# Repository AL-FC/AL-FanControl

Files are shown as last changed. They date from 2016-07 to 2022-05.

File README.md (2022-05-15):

# AL-FanControl

An application-level fan control for desktop PCs
    using Linux, Python, Arduino and PWM fans.

## Architecture

AL-FanControl controls fans according to the system temperature.
The image below shows an exemplary setup of AL-FanControl
    with three processors and two fans.

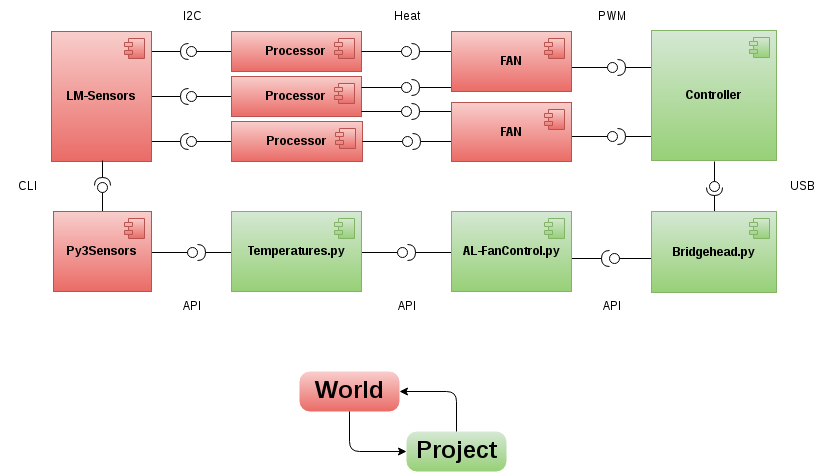
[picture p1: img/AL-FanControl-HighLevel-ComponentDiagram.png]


The main heat sources in modern computers usually expose some sensors via I2C.
These sensors can be read using LM-Sensors via an command line interface.
Py3Sensors provides an API to Python2 and Python3 appications.
This project's `Temperatures.py` reduces Py3Sensors API to temperature sensors.
This project's main application is `AL-FanControl.py`,
    which reacts to changed temperatures with changing the fan setpoints.
To send the setpoints to the controller,
    it uses the API of the `Bridgehead.py`.
The `Bridgehead.py` uses a serial interface (USB)
    to transfer the setpoints to the controller.
The controller controls the fans
    by setting its PWM outputs according to the setpoints.
All fans dissipate heat from surrounding processors.

## Rationale

PC cooling has always been an area of constant change.
In the past,
    ever more power hungry CPUs have lead to
    sophisticated cooling techology.
In combination with more efficient CPUs
    this has enabled smaller and quieter cooling,
    in recent years.
Yet,
    desktop PCs continue to be
    loud at idle and hot under load.
This is an attempt
    at reinventing fan control.
I hope to provoke
    a change in the way we control our fans
    that I feel is long overdue.

Plugging PWM fans into mainboards is a gamble,
    because many built-in fan control do not work properly.
Often PC users are are plagued by
    unnecessary fan noise at idle,
    nervously accelerating fans under short-time load and
    high temperatures at precious hardware.
When swapping
    mainboards, fans or operating systems,
    a previously well-working setup cam misbehave.
Fan controls can be much better and reliable.

Mainboards often only provide a few fan connectors,
    usually three or four.
PC cases come in a plethora of designs
    that feature anywhere from 0 to arbitrarily many fans.
So mainboards
    are notoriously underspecified
    for complex PC builds.
Dedicated hardware
    can control
    the fans
        of a PC
    more scalable
    than mainboards.

The electric motors
    of modern PC fans
    can be regulated via the voltage applied to them.
However,
    many fans
    are not able to
    spin up
    at low voltages.
Assuming fans to be running when they actually fail to spin up
    may lead to unintended actions.
For example,
        the controller may throttle the fans excessively immediately after boot
    and
        only
        apply enough voltage
            for them to spin up,
        when
        the temperatures
            of the components to be cooled
        already exceed limits.
Exceeding temperature limits may lead to
    instability, errors and crashes
    reboots
        when there is a rescue mechanism in place
    or
    increased wear and tear
        when there isn't.
So regulating PC fans
    via voltage is inherently dangerous.
Alternatively,
    some PC fans can be controlled via a digital pulse width modulated (PWM) signal.
With PWM variants of fans costing only little more than the voltage regulated ones,
    choosing PWM fans becomes more and more viable.
Controlling PC fans
    using a digital PWM signal
    is much more reliable,
    because the fans are guaranteed to spin up even at the lowest cycle time.

FanControl is a hardware platform
    for building better fan controls.
It works around
    the often false abstraction
        of the mainboard
    and replaces it with a sane lower-level layer.
Upon this standardised lower-level operation,
    FanControl provides applications easy access to PWM fans.

This repository contains
    a complete chain of open-sourced parts
    necessary to upgrade
        a common desktop PC
        with a software-defined fan control.
These are
    an schematic
        for the neccessary electronics,
    Arduino code
        for the controller-side
    Python code
        for the host-side.

The electronic plans
    comprise
        a breadboard layout,
        electronic schematic and
        platine layout.
They are provided
        in the Fitzing format
    and
        can be be fabricated even at small volumes.

The electronic are based on an
    Atmel 32u4, which
        has hardware USB support
        and
        is fast enough to do PWM in software.
It handles
    the immediate pwm control
        and
    the fan speed sensing.

The Python code
    is structured in layers
        that can be easily replaced by alternative implementaions.
The application level code
    is free of cruft
        and
    can be extended with custom functionality.
Thermal limits and fan caracteristics
    can be defined
    via configuration files.

## Features

-   reusable
    -   Open Source
    -   Open Hardware
-   reproducable
    -   fully documented
    -   fabricatable via Fritzing
-   compact
    -   requires no 3.5"/5.25" bay
    -   fits in a small space inside the case
-   affordable
    -   about 30 € for 1 unit
-   compatible
    -   uses common USB
-   simple protocol
    -   one message to the controller follows one message to the host
-   universal
    -   up to 8 channels for complex PCs

## Design

-   stand-alone hardware that can safely operate during boot/shutdown
-   small Arduino code that only does what it needs to
-   simple protocol that can be easily implemented on the host
-   virtually direct access to PWM from the application level
-   application logic written in Python for easy reimplmentation

## Dependencies

Hardware-level

-   1 free USB port
-   1 free 12 V Molex connector
-   (preferably exclusively) PWM fans

OS-level

-   Linux
-   Python or Python3 or PyPy or PyPy3
-   lm-sensors

Python-level

-   Py3Sensors
-   PySerial

## Bill of Materials

-    6 € Arduino-clone
-   10 € printed circuit board (or a breadboard and good soldering skills)
-   14 € small electronic components

## See also

-   NZXT Grid
    -   10 fans (3-pin molex)
    -   1 channel (3-pin molex)
    -   analog
    -   15 €
    -   up to 30 W
    -   basically an amplifier for an analog fan channel on the mainboard
    -   hardwired (not software-defined)
    -   requires 4-pin molex connector for Power
    -   mounts inside the case
    -   closed source hardware (?)
    -   proprietary protocol (?)

-   [NZXT Grid+ V2](https://www.nzxt.com/product/detail/157-GRID-V2-digital-fan-controller.html)
    -   6 channels
    -   analog (4 - 12 V)
    -   30 €
    -   plugs into mainboard USB headers
    -   requires 4-pin molex connector for Power
    -   mounts inside the case
    -   closed source hardware (?)
    -   proprietary protocol (?)
    -   [CAM](https://cam.nzxt.com/)
        -   Windows (>= 7) GUI
        -   cloud-based data logging and analysis
        -   apps for mobile

-   [AquaComputer OCTO](https://shop.aquacomputer.de/product_info.php?products_id=3832)
    -   8 channels
    -   1 flow sensor input
    -   4 temperature sensor inputs
    -   74,90 €
    -   Controllable via windows-only aquasuite software
    -   Software updates are included only for 6 (!) months

-   [Speedfan](http://www.almico.com/speedfan.php)
    -   windows-only software
    -   GUI
    -   controls the fan controllers on a mainboard

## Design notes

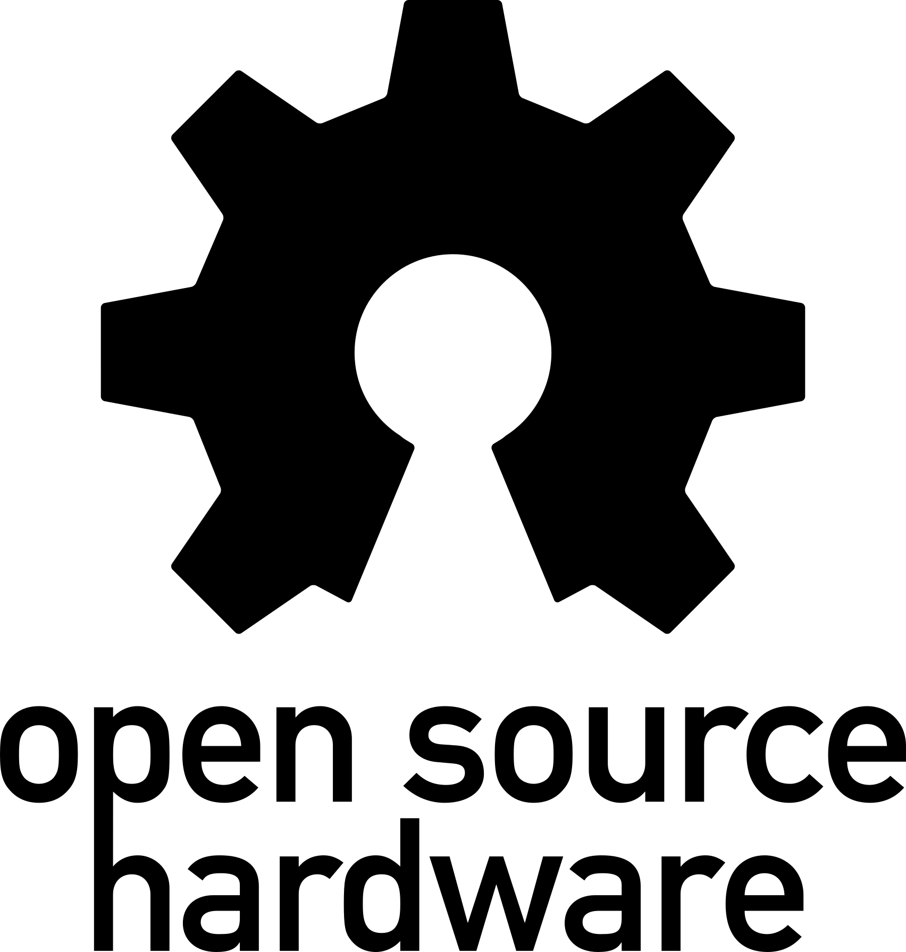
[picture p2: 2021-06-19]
img/oshw_black.png

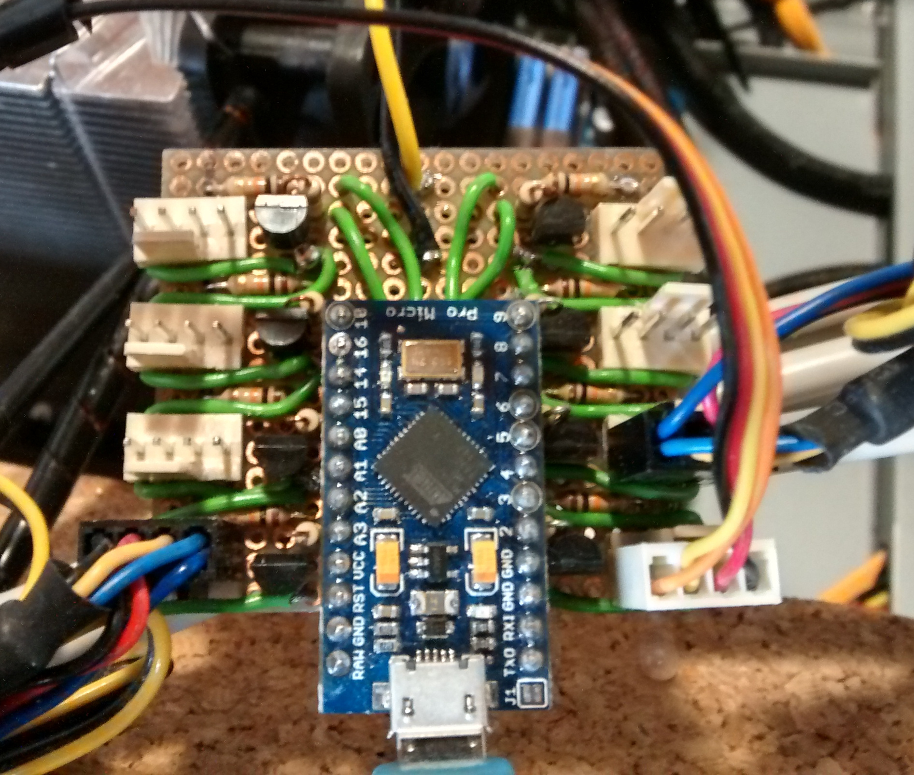
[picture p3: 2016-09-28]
fritzing/IMG_20151219_143207_cut.jpg

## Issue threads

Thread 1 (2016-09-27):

USB Breakout?

Lugoues, 2016-09-27:
Should probably add a usb breakout for this, no?

Lugoues, 2016-09-28:
Ah,  I see. I should just use a Pro Micro and no usb breakout needed! :)

Bengt, 2016-09-28:
Yes, the Pro Micro acts as an interface between USB and PWM. I uploaded [a photo of the board I am using](https://github.com/Bengt/AL-FanControl/blob/master/fritzing/IMG_20151219_143207_cut.jpg) since about a year, now. Be advised though, that it outputs a 12 V PWM signal, although the PWM specification says it should be 5 V. This was an misunderstanding I made at the time. As it turns out, my fans are tolerant to 12 V PWM inputs, so I never bothered to revise the board and Fritzing. The circuit can be made much simpler, if one uses the 5 V outputs of the Pro Micro directly, so patches are definitely welcome!

Lugoues, 2016-09-28:
The diagram already shows the 5v pin of the molex connector driving the whole thing. Your picture looks like you hooked up the 12v (yellow wire)?

Bengt, 2016-09-28:
Nice spot. That would be a bug in the Fritzing file, then. I meant to use the 12 V rail and must have misinterpreted the Molex connector. Yes, my board is hooked up to 12 V as originally intended.

Closed 2016-09-28.

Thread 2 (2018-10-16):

More than 4 PWM fan 25Khz ?

Lemania, 2018-10-16:
Hi
you managed to control more than 4 fan at 25khz ?

thanks
Best regards
Sébastien

Bengt, 2018-10-16:
Yes. I had up to 8 fans running over PWM.

Lemania, 2018-10-16:
Super !

I will look in detail and download fritzing to see your schematic

thanks to your work
Best regard
Sébastien

Bengt, 2018-10-17:
Thanks for your interest in this. I do not use the fan controller anymore, so the code has gone stale. Anyway, I just pushed the latest version I was using until about half a year ago.

Lemania, 2018-10-17:
Thanks,  I have an nzxt grid-plus-v3 and I do not like the CAM app

I have two xeon,16 core and CAM does not allow to choose the CPU that you want, or even take a temperature average on the core or the package. So the fans fluctuates...

I also noticed that CAM was using a lot of bandwidth, and we do not know exactly which data is going through

Lemania, 2018-10-17:
so you no longer use transtor in the latest version ?

Bengt, 2018-10-18:
Yes, I think the output buffering is unnecessary.

Lemania <notifications@github.com> schrieb am Mi., 17. Okt. 2018, 13:02:

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

Bengt, 2018-10-19:
Interesting that CAM tends to oscillate the fan speed for you. I managed to run into oscillation with my new motherboard (X399 Taichi), too. Maybe I can still benefit from a stand-alone fan controller ...

I used this on an AMD Phenom II X6, so you will have to adapt the sensor data parsing to fit your machine.

Feel free to send me pull requests for any changes you make to the source code.

Bengt, 2018-10-19:
I used an Arduino Pro Micro Clone off Aliexpress. Just like this one:

https://de.aliexpress.com/item//32860810419.html

Lemania, 2019-07-04:
Hello, I resume the project after a break, I now have a mega32u4.

You did not answer a question, you get out 25khz on each output ?

thanks
best regards
Sébastien

Bengt, 2022-05-15:
Sorry for replying only now. I just looked into that for a different reason. None of the analog outputs can provide exactly 25 kHz. However, you can configure all of the analog outputs to generate either 31250 or 7813 Hz, both of which are sufficiently close to the PWM specification for all fans I tested, at least. For details on how to do that, please refer to the source code documentation in this file:

https://github.com/AL-FC/AL-FanControl/blob/master/arduino/bridgehead2/bridgehead3_Mega_v5.0.7/bridgehead3_Mega_v5.0.7/bridgehead3_Mega_v5.0.7.ino

Bengt, 2022-05-15:
With that, I feel like this question is answered and actually implemented in working code for the microcontroller in the scope of this project. Therefore, I am closing this issue.

Closed 2022-05-15.

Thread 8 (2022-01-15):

Space out fan headers

Bengt, 2022-01-15:
Currently, the casings collide

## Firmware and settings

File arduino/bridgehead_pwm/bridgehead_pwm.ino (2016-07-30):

/*
                Fast PWM Test

Demostrates the generation of high speed PWM
using timers 1 and 4
There are two pieces of code:

One for pins 9, 10 and 11 using TIMER 1
with frequencies up to 62kHz

Other for pins 5 and 6 using TIMER 4
with frequencies up to 187kHz

*/

int pin_pulse = 7;


/**********************************************************
   Fast PWM on pins 9,10,11 (TIMER 1)
   
   Do not use analogWrite to pins 9, 10 or 11 if using 
   this functions as they use the same timer.
   
   Those functions will probably conflict with the 
   servo library.
   
   Uses 5 PWM frequencies between 61Hz and 62.5kHz
   
**********************************************************/

// Frequency modes for TIMER1
#define PWM62k   1   // 62500 Hz
#define PWM8k    2   //  7812 Hz
#define PWM1k    3   //   976 Hz
#define PWM244   4   //   244 Hz
#define PWM61    5   //    61 Hz

// Direct PWM change variables
// OCR = output compare register
#define PWM9   OCR1A
#define PWM10  OCR1B
#define PWM11  OCR1C

// Configure the PWM clock
// The argument is one of the 5 previously defined modes
void pwm91011configure(int mode) {
  // Configure DDRB
  // DDRB is the Port B Data Direction Register.
  DDRB |= 1 << 5;  // Set port B pin 5 (Arduino 9) to output mode
  DDRB |= 1 << 6;  // Set port B pin 6 (Arduino 10) to output mode
  DDRB |= 1 << 7;  // Set port B pin 7 (Arduino 11) to output mode

  // Configure TCCR1A
  //  00 : Channel A disabled D9
  //  00 : Channel B disabled D10
  //  00 : Channel C disabled D11
  //  01 : Fast PWM 8 bit
  // TCCR1A is the Timer/Counter1 Control Register A.
  TCCR1A = 1;      // Set prescaler to 1, to increment at 16 MHz
  TCCR1A |= 0x80;  // Activate channel 5
  TCCR1A |= 0x20;  // Activate channel 6
  TCCR1A |= 0x08;  // Activate channel 7

  // Configure TCCR1B
  // TCCR1B is the Timer/Counter 1 Control Register B.
  // Clock mode and Fast PWM 8 bit
  TCCR1B = mode | 0x08;

  // Configure TCCR1C
  // TCCR1C is the Timer/Counter 1 Control Register C.
  TCCR1C = 0;      // Stop timer/counter channel c
}

/**********************************************************
   Fast PWM on pins 5, 6 (High Speed TIMER 4)
   
   Do not use analogWrite to pins 5 or 6 if using 
   this functions as they use the same timer.
   
   Those functions will conflict with the 
   MSTIMER2 library.

   Uses 7 PWM frequencies between 2930Hz and 187.5kHz
   
   Timer 4 uses a PLL as input so that its clock frequency
   can be up to 96MHz on standard Arduino Leonardo.
   We limit imput frequency to 48MHz to generate 187.5kHz PWM
   If needed, we can double that up to 375kHz

**********************************************************/

// Frequency modes for TIMER4
#define PWM187k 1   // 187500 Hz
#define PWM94k  2   //  93750 Hz
#define PWM47k  3   //  46875 Hz
#define PWM23k  4   //  23437 Hz
#define PWM12k  5   //  11719 Hz
#define PWM6k   6   //   5859 Hz
#define PWM3k   7   //   2930 Hz

// Direct PWM change variables
#define PWM5 OCR4A
#define PWM6 OCR4D

// Configure the PWM clock
// The argument is one of the 7 previously defined modes
void pwm_5_6_configure(int mode) {
  // TCCR4A configuration
  TCCR4A |= 0x42; // Activate the complementary channel A (Arduino pin 5)
 
  // TCCR4B configuration
  TCCR4B = mode;
  
  // TCCR4C configuration
  TCCR4C |= 0x09;  // Activate channel C

  // TCCR4D configuration
  TCCR4D = 0;      // operate in PWM mode

  OCR4C = 255;     // Terminal count for Timer 4 PWM
  
  // Configure Port C
  DDRC |= 1 << 6;  // Set port C pin 6 (Arduino 5) to output mode
  DDRD |= 1 << 7;  // Set port D pin 7 (Arduino 6) to output mode
 
  // PLL Configuration
  // Use 96MHz / 2 = 48MHz
  PLLFRQ = (PLLFRQ & 0xCF)|0x30;
  // PLLFRQ = (PLLFRQ & 0xCF)|0x10; // Will double all frequencies
}

void setup() {
  // Configure Timer 1 (Pins 9, 10 and 11)
  // It will operate at 8 kHz
  // Valid options are: 
  //      PWM62k, PWM8k, PWM1k, PWM244 and PWM61
  // This works with Arctic Cooling AF12 und Noctua NF-F12.
  pwm91011configure(PWM8k);

  // Configure Timer 4 (Pins 5 and 6)
  // It will operate at 23 kHz
  // Valid options are:
  //     PWM187k, PWM94k, PWM47k, PWM23k, PWM12k, PWM6k and PWM3k
  pwm_5_6_configure(PWM23k);

  Serial.begin(9600);

  pinMode(pin_pulse, INPUT_PULLUP);
}

int min_int(int one, int other) {
  if (one < other)
    return one;
  return other;
}

int max_int(int one, int other) {
  if (one > other)
    return one;
  return other;
}

int rpm_target = 200;
int pwm_value = 40;
int pwm_min = 28;
int pwm_max = 255;
bool upwards = true;

/*
 * free air
 * PWM - RPM - ticking
 *   0 - off/restart
 *   1 - off/restart
 *   2 - off/restart
 *   3 - off/restart
 *   4 - off/restart
 *   5 - off/restart
 *   6 - off/restart
 *   7 - off/restart
 *   8 - off/restart
 *   9 - off/restart
 *  10 - off/restart
 *  11 - off/restart
 *  12 - off/restart
 *  13 - off/restart
 *  14 - off/restart
 *  15 - off/restart
 *  16 - off/restart
 *  17 - off/restart
 *  18 - off/restart
 *  19 - off/restart
 *  20 - off/restart
 *  21 - off/restart
 *  22 - off/restart
 *  23 - off/restart
 *  24 - off/restart
 *  25 - off/restart
 *  26 - off/restart
 *  27 - off/restart
 *  28 -  120
 *  32 -  180 - faint
 *  40 -  240 - yes
 *  48 -  360 - yes
 *  64 -  480 - yes
 *  96 -  840 - yes
 * 128 - 1140 - yes
 * 130 - 1140 - yes
 * 135 - 1140 - yes
 * 138 - 1200 - yes
 * 140 - 1200 - yes
 * 150 - 1320 - faint
 * 153 - 1320 - faint
 * 155 - 1380 - no
 * 160 - 1380 - no
 * 256 - off - no
 */

void loop() {
  unsigned long pulseDuration = pulseIn(pin_pulse, LOW);
  double frequency = 1000000 / pulseDuration;
  int rpm_current = (int) frequency / 4 * 60;
  Serial.print("RPM:");
  Serial.println(rpm_current);

  // target rpm
/*
  if (rpm_current < rpm_target - 1.5 / 255.0 * rpm_target)
    pwm_value = min_int(pwm_value + 1, 255);
  if (rpm_current > rpm_target + 1.5 / 255.0 * rpm_target)
    pwm_value = max_int(pwm_value - 1, 0);
*/


  // sweep rpm
  if (pwm_value == pwm_min)
    upwards = true;
  if (pwm_value == pwm_max)
    upwards = false;
  if (upwards)
    pwm_value = pwm_value + 1;
  else
    pwm_value = pwm_value - 1;

  // Those fast macros require a previous configuration
  // of the channels using the pwmSet9 and pwmSet6
  // functions
  // PWMn macros are fast to execute
  PWM5 = 255 - pwm_value;
  PWM6 = pwm_value;
  PWM9 = pwm_value;
  PWM10 = pwm_value;
  PWM11 = pwm_value; // TODO there is no pin 11 on the leonardo clones, I am using

  Serial.print("PWM:");
  Serial.println(pwm_value, DEC);

  // Small delay
  delay(100);
}

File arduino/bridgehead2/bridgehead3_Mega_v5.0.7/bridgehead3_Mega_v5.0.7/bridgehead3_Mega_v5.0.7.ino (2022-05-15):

//                   FAN_{  15,   7,   6,   5,   4,   3,   2,   1,   0,   8,   9,  10,  11,  12,  13,  14}
const int PINS_PULSE[] = { A14,  21,  20,  19,  18,  17,  16,  15,  14,  A0,  A2,  A4,  A6,  A8, A10, A12};
//                    Log{ INF;0.50;0.49; INF;0.48;0.47;0.44;0.47;0.47;0.47;0.43; INF;0.47;0.48; INF;0.48}
//            Pulse works{  No, Yes, Yes, Yes, Yes, Yes, Yes, Yes, Yes, Yes, Yes, Yes, Yes, Yes, Yes, Yes}
const int PINS_PWM[] =   {   1,   2,   3,   4,   5,   6,   7,   8,   9,  10,  11,  12,  13,  45,  46,  44};
//            PWM   works{  No, Yes, Yes, Yes, Yes, Yes, Yes, Yes, Yes, Yes, Yes, Yes, Yes, Yes, Yes, Yes}
const int MICROSECONDS_IN_ONE_SECOND = 1000000;

void setup() {
    const int PWM_FREQUENCY_TARGET = 24000;

    // The base frequency for pins 2, 3, 5, 6, 7, 8, 9, 10, 11, 12, 44, 45, and 46 is 31250 Hz
    // Allowed divisors are always 1 and 8; we don't need to worry about the rest for PWM fans.
    // So set a pin's PWM frequency of each clock to 31250 Hz / 1 = 31250 Hz ~ 125 % of 25000 Hz
    // TCCR3B
    setPwmFrequency( 2, 1);
    setPwmFrequency( 3, 1);
    setPwmFrequency( 5, 1);
    // TCCR4B
    setPwmFrequency( 6, 1);
    setPwmFrequency( 7, 1);
    setPwmFrequency( 8, 1);
    // TCCR2B
    setPwmFrequency( 9, 1);
    setPwmFrequency(10, 1);
    // TCCR1B
    setPwmFrequency(11, 1);
    setPwmFrequency(12, 1);
    // TCCR5B
    setPwmFrequency(44, 1);
    setPwmFrequency(45, 1);
    setPwmFrequency(46, 1);

    // The base frequency for pins 4, and 13 is 62500 Hz
    // Allowed divisors are always 1 and 8; we don't need to worry about the rest for PWM fans.
    // Set pin 4's PWM frequency of their clock to 62500 / 8 = 7813 Hz ~ 31 % of 25000 Hz
    // Set pin 13's PWM frequency of their clock to 62500 / 8 = 7813 Hz ~ 31 % of 25000 Hz
    // TCCR0B
    setPwmFrequency(4, 8);
    setPwmFrequency(13, 8);

    // space out fan speeds a bit to avoid some resonance
    int pwms[16] = {46, 47, 48, 49, 50, 51, 52, 53, 54, 55, 56, 57, 58, 59, 60, 61};

    // Shuffle PWM values to load fans randomly
    for (int i = 0; i < 16 - 1; i++) {
        int j = random(0, 16 - i);

        int t = pwms[i];
        pwms[i] = pwms[j];
        pwms[j] = t;
    }

    // Send a start up pulse
    setPwms(pwms);

    // Initialize pulse pins
    for (int i = 0; i < 16; i++)     
        pinMode(PINS_PULSE[i], INPUT_PULLUP);

    const int SERIAL_BD_RATE = 19200;
    //Serial.begin(SERIAL_BD_RATE);

    // Sending data to the host seems to mess up the timing.
    // So don't do that to preserve that last timer for PWM, too.
    //Serial.println("");
    //Serial.println("Setup done");
}

int* messageToPwms(String message) {
    // Caution: Non-reentrant return value.
    static int pwms[16];

    int separator_position;
    for (int i = 0; i < 16; i++) {
        // Determine next separator
        separator_position = message.indexOf(';');
  
        // Parse value left of a ';' 
        pwms[i] = message.substring(0, separator_position).toInt();

        // Strip part left of a ';' from message
        message = message.substring(separator_position + 1);
    }

    return pwms;
}

void logPulseIntervals() {
    String pulseDurations = "";

    // Collect pulse durations from all fans into a message
    for (int i = 0; i < 16; i++)
        pulseDurations = \
            pulseDurations + \
            String(
                float(MICROSECONDS_IN_ONE_SECOND) /
                pulseIn(PINS_PULSE[i], LOW, 200000)
            ) + \
            ";";

    // Log message to the host via the serial interface
    //Serial.println(pulseDurations);
}

void setPwms(int pwms[]) {
    // Set PWM value to each fan
    for (byte channel_index = 0; channel_index < 16; channel_index++)
        analogWrite(PINS_PWM[channel_index], pwms[channel_index]);
}

String LAST_MESSAGE = "";
void loop() {
    // Get message from serial console
    String message = "";
    while (Serial.available())
        message.concat((char) Serial.read());

    if (message == "") {
        if (LAST_MESSAGE == "") {
            // We have never gotten a message.
            // So keep waiting for one.
            return;
        } else {
            // We have not gotten a message this time, but last time.
            // So use the last message as our current one.
            message = LAST_MESSAGE;
            // We already know that the current message equals last message.
            // So log the pulse intervals.

            // Sending data to the host seems to mess up the timing.
            // So don't do that to preserve that last timer for PWM, too.
            // logPulseIntervals();
        }
    } else {
        // We got a message this time.
        if (LAST_MESSAGE == message) {
            // This message was repeated by the host.
            // So log the pulse intervals.

            // Sending data to the host seems to mess up the timing.
            // So don't do that to preserve that last timer for PWM, too.
            // logPulseIntervals();            
        } else {
            // This message was new.
            // So update the last message.
            LAST_MESSAGE = message;
            // Also update the PWMs and the log pulse intervals.
            setPwms(messageToPwms(message));
            // Sending data to the host seems to mess up the timing.
            // So don't do that to preserve that last timer for PWM, too.
            // logPulseIntervals();
        }
    }

    // Sending data to the host seems to mess up the timing.
    // So don't do that to preserve that last timer for PWM, too.
    //Serial.println(".");
}
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

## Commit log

2015-10-06 initial sensor readout
2015-10-18 dumpy commit because I am tired
2015-11-09 Update README.md
    process input from the current c't (24/15)
2015-11-09 add pamphlet on voltage regulation
2016-03-08 wrap get_temps into function to isolate sensors package usage
2016-03-08 add integration test for temperatures
2016-03-08 add unit test for temperatures
2016-03-08 dump all failed attempts
    [blink_isr.ino.ino, bridgehead5V_ino.ino, bridgehead_5V_Demo_py.ino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]
2016-03-08 add the finally working attempt at a pwm fan controller
2016-07-30 add first version of the pcb, can be much simpler
    [UberPWM2.fzz]
2016-07-30 use internal pullups for pulse pin
2016-07-30 Initial implementation of (almost?) all hardware pwm pins on the flyduino
2016-07-30 update nosetests.json to current code layout
2016-09-28 Add image of my current USB interface
2016-09-28 Multiple things:
    - Introduce state borg object to avoid passing it around everywhere
    - Reduce visibility of internal functions
    - extend documentation
    - use relative imports to make command line usage easier
    [temperatures.py]
2018-10-17 dump my last used version of everything
    [UberPWM2.fzz, UberPWM3.fzz, UberPWM3_compact.fzz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]
2021-06-19 add the last three revisions of the PWM adapter shield
    [UberPWM4.fzz, UberPWM4_autoroute.fzz, UberPWM4_autoroute2.fzz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]
2021-06-19 update fritzing file
    [UberPWM5_PCB_v.5.0.8.fzz]
2022-05-15 Fix documentation about setting the PWM frequency
    [bridgehead3_Mega_v5.0.7.ino]
